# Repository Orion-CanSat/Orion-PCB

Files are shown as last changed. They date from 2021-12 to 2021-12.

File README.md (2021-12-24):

# Orion II PCB

&nbsp;
## Who are we?
We are a team composed of 12 students of the [Model High School “Evangeliki Scholi Smyrna”](http://lyk-evsch-n-smyrn.att.sch.gr/wordpress/?p=1322). For the fourth consecutive time we are participating in the Panhellenic competition "[CanSat in Greece](https://cansat.gr/)", a qualifier of the Pan-European competition "[CanSats in Europe](http://www.esa.int/SPECIALS/CanSat/SEMXTDCKP6G_0.html)", organized by ESA (European Space Agency) for the last 8 years. Our team is called Orion II and our supervisor is Dr. Christos Fanidis.

&nbsp;
## Our Inspiration

&nbsp;
## Do you want to contibute?
Unfortuannately this repository does not accept any new commits, or merge requests. You are free to fork it and work on your own.

&nbsp;
## PCB Desgin
These PCBs where designed by Danae Veli.

&nbsp;
## Meet our Team (In alphabetical order)
| Name | Role | Introduction |
| --- | --- | --- |
| __Danae Veli__ | Head of Electrical Engineering | My name is Danae Veli and I am a student at Model High School "Evangeliki Scholi Smyrna". I am a part of team Orion II and I am in charge of the electrical design. My main duty is to design the PCBs for the project. |
| [__Dionysios Angelopoulos__](https://github.com/DennisAngelo) | Head of Mechanical Engineering and Control Systems Development | My name is Dionysios Angelopoulos. I am a greek High School student attending Model High School “Evangeliki Scholi Smyrna”. I am the head of Mechanical Engineering in Orion II. My main duty was to 3D model the cansat and to design and tune the control system for the cansat.  |
| [__Jim Balatos__](https://github.com/jbalatos) | Head of Software Engineering | My name is Jim Balatos. I am a greek High School student attending Model High School “Evangeliki Scholi Smyrna”. I am the head of Software Engineering in Orion II. My main duty was to write the Live Server of our mission. |
| __Giorgos Kaltsis__ | Senior Data Analyst | |
| [__Konstantinos Kritharidis__](https://github.com/konstantinosk31) | Head of Retrieval System | My name is Konstantinos Kritharidis. I am a greek High School student attending The American College of Greece - Pierce. I am the head of the Retrieval System in Orion II. My main duty was to design and create the ram-air parachute for the CanSat. |
| [__Rikarnto Bariampa__](https://github.com/richardbar) | Head of Telemetry and Senior Software Engineer | My name is Rikarnto Bariampa. I am a greek High School student attending Model High School “Evangeliki Scholi Smyrna”. I am the head of Telemetry and a Senior Software Engineer in Orion II. My main duty was to write the onboard code for the CanSat. |

&nbsp;
## Want to reach us?
If you have any question, please feel free to reach us in one of the following ways:
* [__Email__](mailto:orioncantgr@gmail.com)
* [__Facebook__](https://www.facebook.com/orioncansatteam)
* [__Twitter__](https://twitter.com/OrionCanSat2020)

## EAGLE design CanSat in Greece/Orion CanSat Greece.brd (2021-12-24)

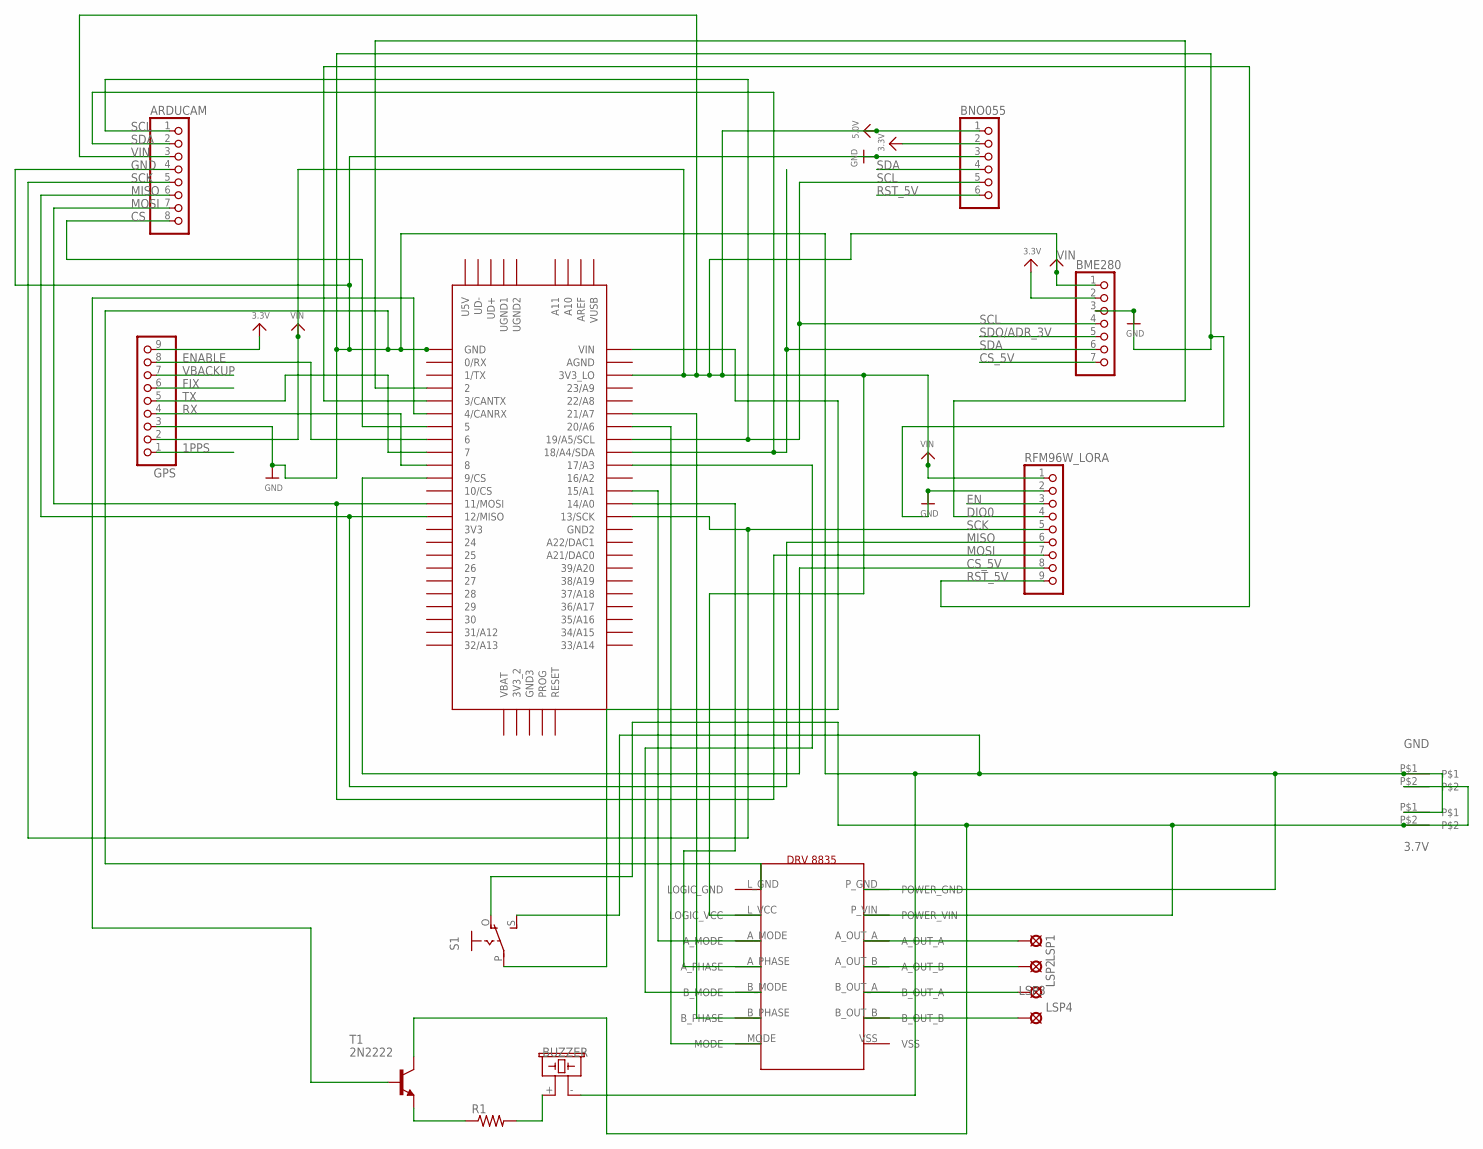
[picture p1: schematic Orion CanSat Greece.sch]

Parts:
ARDUCAM: PINHD-1X8BIG; 1X08-BIG
BME280: HEADER-1X770MIL; 1X07_ROUND_70
BNO055: HEADER-1X676MIL; 1X06_ROUND_76
GPS: HEADER-1X970MIL; 1X09_ROUND_70
LSP1, LSP2, LSP3, LSP4: LSP13
R1: FLIPFLOP-RES; 0805-THM
RFM96W_LORA: HEADER-1X970MIL; 1X09_ROUND_70
S1: EG1218S; EG1218
SG2: F/CM12P
T1: 2N2222; TO92-EBC-OVAL
U$1: TEENSY_3.5/3.6
U$7, U$8: 2PINS
U$15: DRV8835

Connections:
1PPS: GPS.1
3.3V: BME280.2, BNO055.2, GPS.9
3V7: S1.P, U$1.VIN
BZPWR: R1.2, SG2.+ (1)
CS: ARDUCAM.8, U$1.5
CS_5V: BME280.7, RFM96W_LORA.8, U$1.9/CS
DIO0: RFM96W_LORA.4, U$1.2
EN: RFM96W_LORA.3
ENABLE: GPS.8, U$1.6
FIX: GPS.6
GND: ARDUCAM.4, BME280.3, BNO055.3, GPS.3, RFM96W_LORA.2, S1.S, SG2.- (2), U$1.GND, U$7.P$1, U$8.P$1, U$15.L_GND (LOGIC_GND), U$15.P_GND (POWER_GND)
MISO: ARDUCAM.6, RFM96W_LORA.6, U$1.12/MISO
MOSI: ARDUCAM.7, RFM96W_LORA.7, U$1.11/MOSI
unnamed: R1.1, T1.E
unnamed: U$1.20/A6, U$15.MODE
unnamed: T1.B, U$1.4/CANRX
unnamed: U$1.21/A7, U$15.B_PHASE
unnamed: U$1.14/A0, U$15.A_PHASE
unnamed: U$1.15/A1, U$15.A_MODE
unnamed: U$1.17/A3, U$15.B_MODE
unnamed: LSP1.MP, U$15.A_OUT_A
unnamed: LSP2.MP, U$15.A_OUT_B
unnamed: LSP3.MP, U$15.B_OUT_A
unnamed: LSP4.MP, U$15.B_OUT_B
RST_5V: BNO055.6, RFM96W_LORA.9, U$1.3/CANTX
RX: GPS.4, U$1.8
SCK: ARDUCAM.5, RFM96W_LORA.5, U$1.13/SCK
SCL: ARDUCAM.1, BME280.4, BNO055.5, U$1.19/A5/SCL
SDA: ARDUCAM.2, BME280.6, BNO055.4, U$1.18/A4/SDA
SDO/ADR_3V: BME280.5
TX: GPS.5, U$1.7
VBACKUP: GPS.7
VBAT: S1.O, T1.C, U$7.P$2, U$8.P$2, U$15.P_VIN (POWER_VIN)
VIN: ARDUCAM.3, BME280.1, BNO055.1, GPS.2, RFM96W_LORA.1, U$1.3V3_LO, U$15.L_VCC (LOGIC_VCC)

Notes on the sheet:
3.7V
GND
BUZZER
VIN

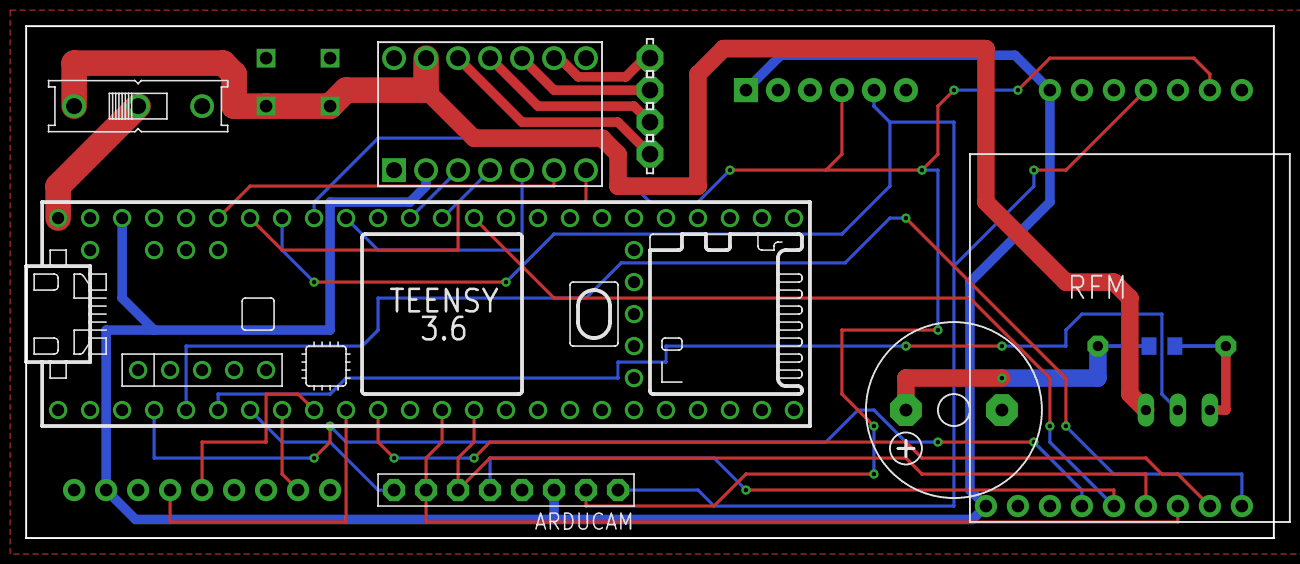
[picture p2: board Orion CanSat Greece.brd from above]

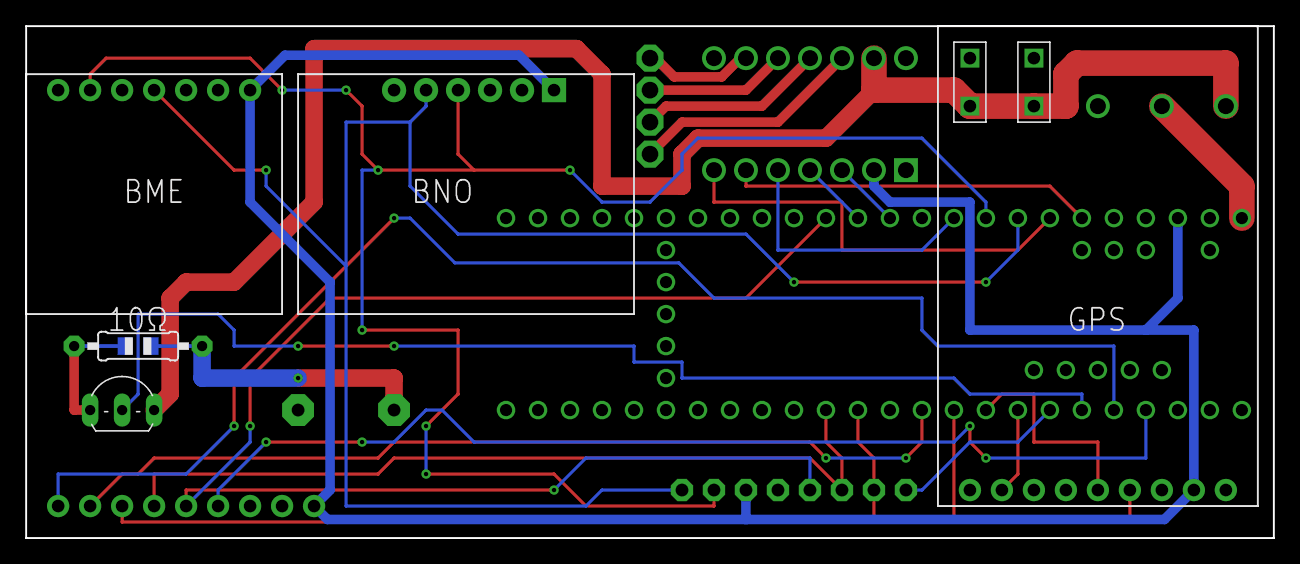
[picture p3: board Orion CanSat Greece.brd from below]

Board: 2 copper layers, 99.1 x 40.6 mm, 17 parts (4 on the bottom side), 29 nets.

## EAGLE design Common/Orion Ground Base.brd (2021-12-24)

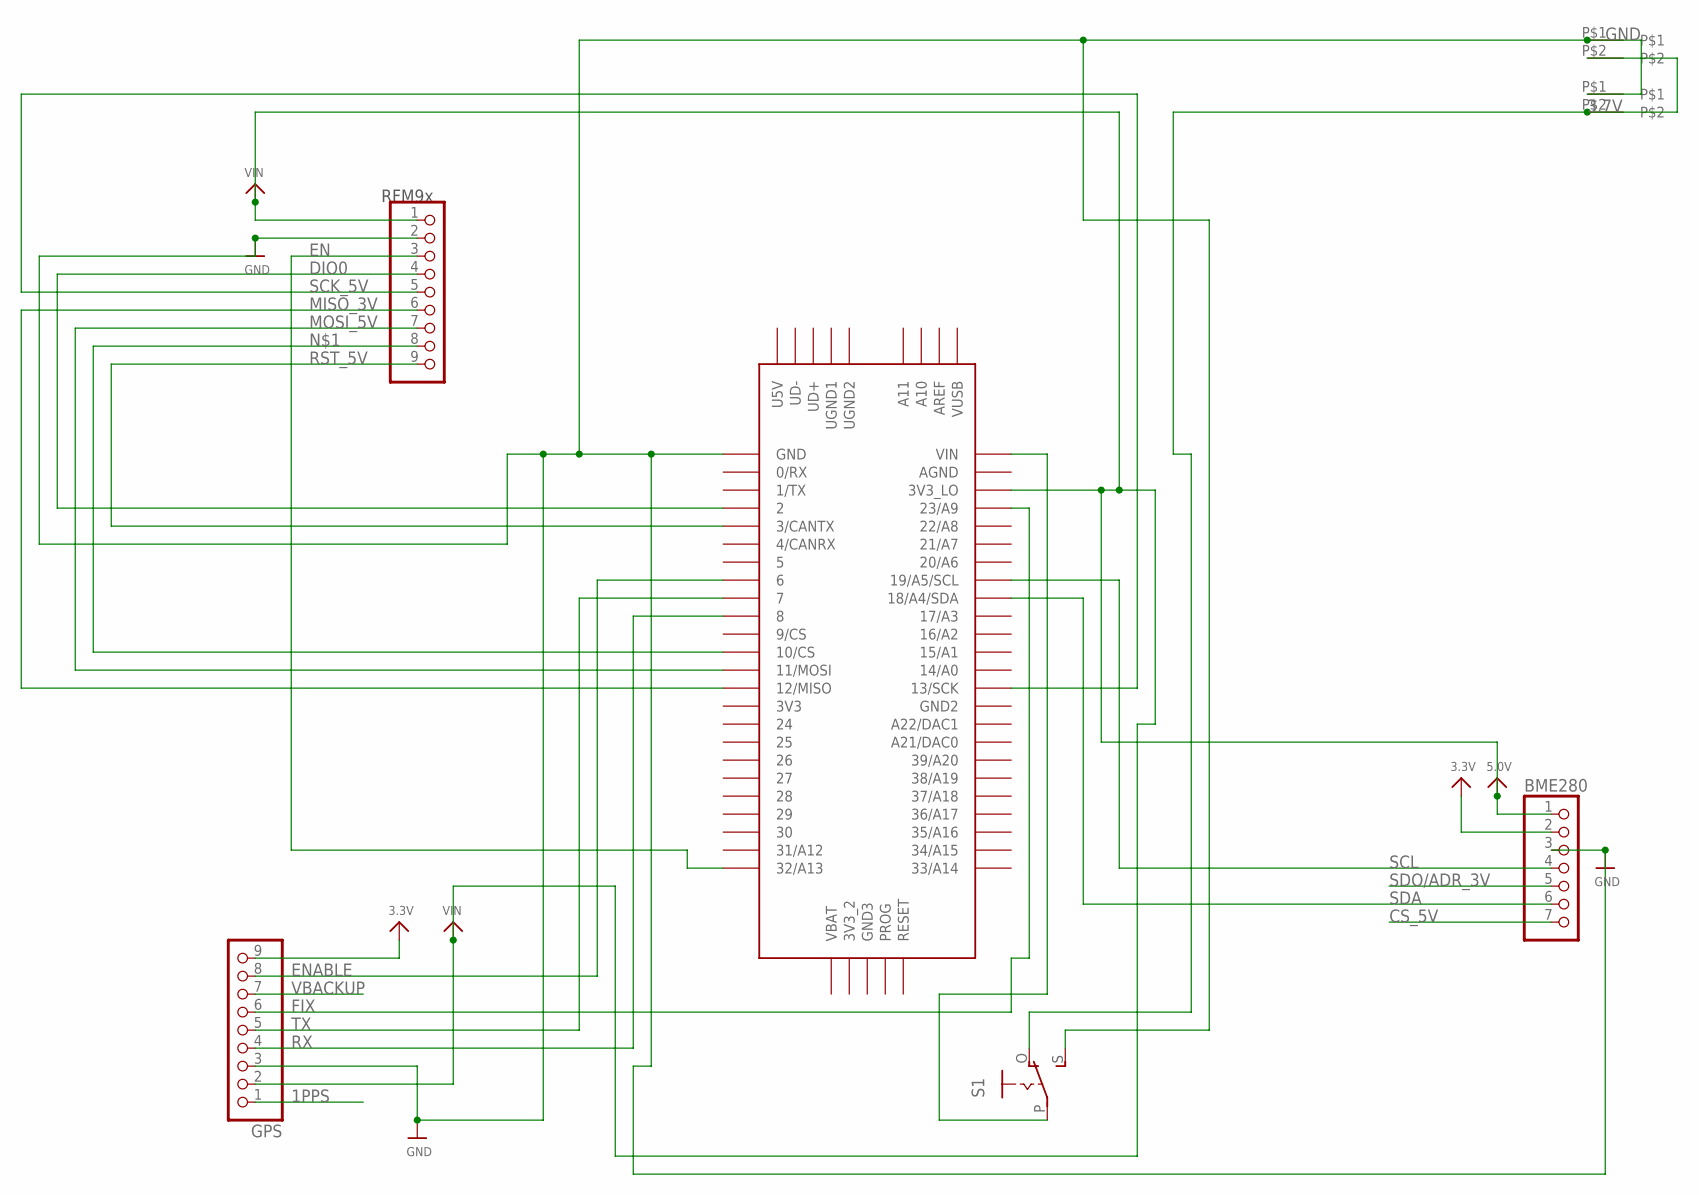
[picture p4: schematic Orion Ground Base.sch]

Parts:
BME280: HEADER-1X770MIL; 1X07_ROUND_70
GPS: HEADER-1X970MIL; 1X09_ROUND_70
JP3: HEADER-1X970MIL; 1X09_ROUND_70
S1: EG1218S; EG1218
U$1: TEENSY_3.5/3.6
U$7, U$8: 2PINS

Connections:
1PPS: GPS.1
3.3V: BME280.2, GPS.9
CS_5V: BME280.7
DIO0: JP3.4, U$1.2
EN: JP3.3, U$1.32/A13
ENABLE: GPS.8, U$1.6
FIX: GPS.6, U$1.23/A9
GND: BME280.3, GPS.3, JP3.2, S1.S, U$1.GND, U$7.P$1, U$8.P$1
MISO_3V: JP3.6, U$1.12/MISO
MOSI_5V: JP3.7, U$1.11/MOSI
unnamed: JP3.8, U$1.9/CS, U$1.10/CS
unnamed: S1.P, U$1.VIN
unnamed: S1.O, U$7.P$2, U$8.P$2
RST_5V: JP3.9, U$1.3/CANTX
RX: GPS.4, U$1.8
SCK_5V: JP3.5, U$1.13/SCK
SCL: BME280.4, U$1.19/A5/SCL
SDA: BME280.6, U$1.18/A4/SDA
SDO/ADR_3V: BME280.5
TX: GPS.5, U$1.7
VBACKUP: GPS.7
VIN: BME280.1, GPS.2, JP3.1, U$1.3V3_LO

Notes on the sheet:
RFM9x
3.7V
GND

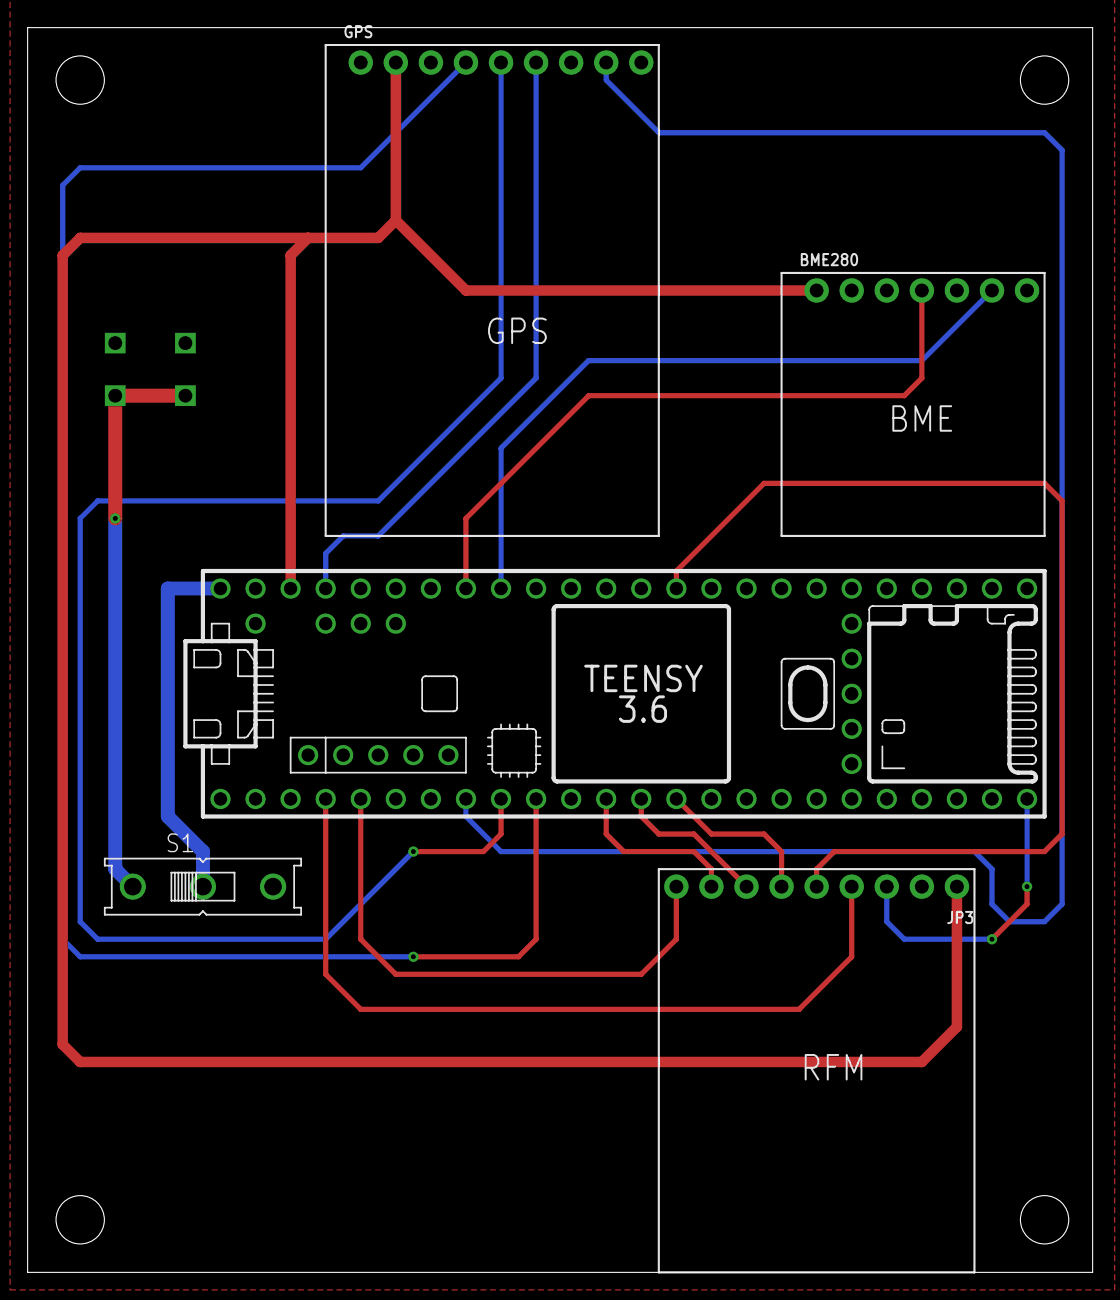
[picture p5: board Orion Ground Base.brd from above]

Board: 2 copper layers, 77.1 x 90.2 mm, 7 parts (0 on the bottom side), 18 nets.

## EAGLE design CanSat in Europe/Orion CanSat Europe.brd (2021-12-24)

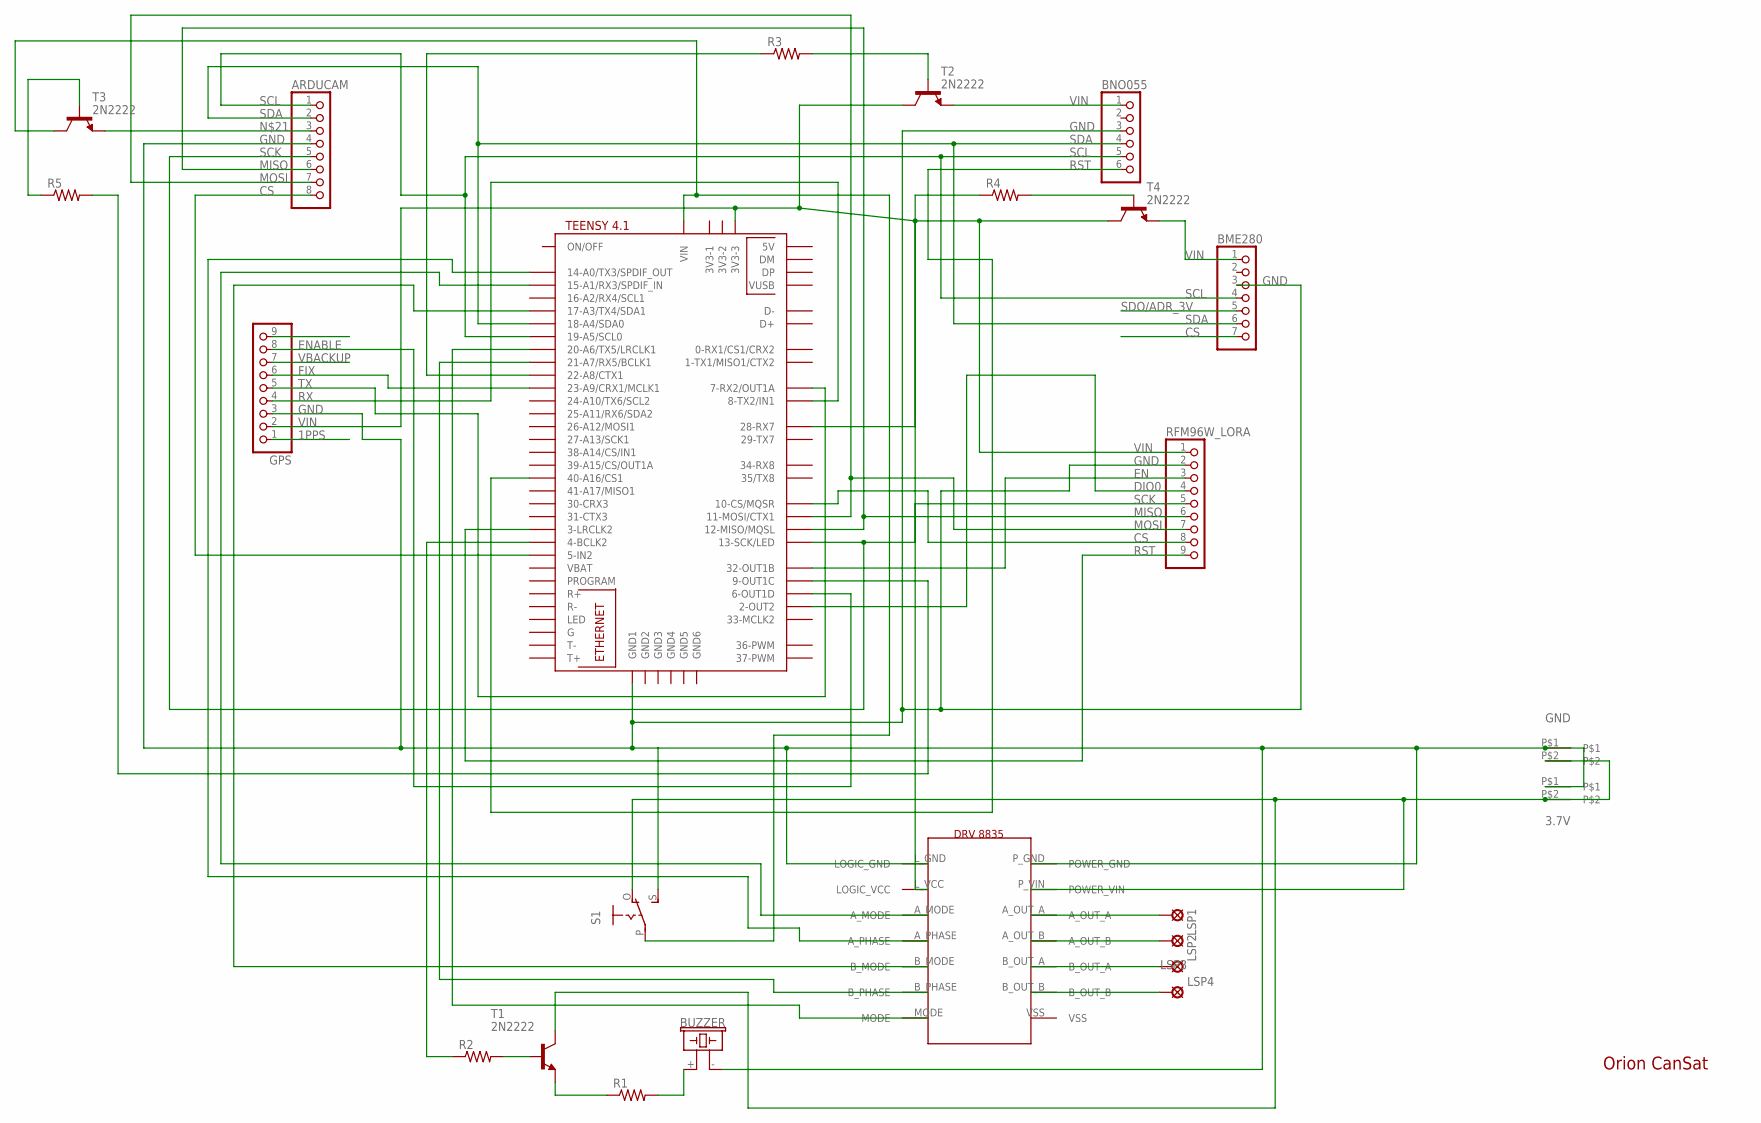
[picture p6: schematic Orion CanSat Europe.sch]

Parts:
ARDUCAM: PINHD-1X8BIG; 1X08-BIG
BME280: HEADER-1X770MIL; 1X07_ROUND_70
BNO055: HEADER-1X676MIL; 1X06_ROUND_76
GPS: HEADER-1X970MIL; 1X09_ROUND_70
LSP1, LSP2, LSP3, LSP4: LSP13
R1, R2, R3, R4, R5: FLIPFLOP-RES; 0805-THM
RFM96W_LORA: HEADER-1X970MIL; 1X09_ROUND_70
S1: EG1218S; EG1218
SG2: F/CM12P
T1, T2, T3, T4: 2N2222; TO92-EBC-OVAL
U$1: DRV8835
U$5: TEENSY41
U$7, U$8: 2PINS

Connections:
1PPS: GPS.1
BZPWR: R1.2, SG2.+ (1)
CS: ARDUCAM.8, U$5.5-IN2
CS_5V: BME280.7, RFM96W_LORA.8, U$5.10-CS\MQSR (10-CS/MQSR)
DIO0: RFM96W_LORA.4, U$5.2-OUT2
EN: RFM96W_LORA.3, U$5.32-OUT1B
ENABLE: GPS.8, U$5.6-OUT1D
FIX: GPS.6, U$5.23-A9/CRX1/MCLK1
GND: ARDUCAM.4, BME280.3, BNO055.3, GPS.3, RFM96W_LORA.2, S1.S, SG2.- (2), U$1.L_GND (LOGIC_GND), U$1.P_GND (POWER_GND), U$5.GND1, U$7.P$1, U$8.P$1
MISO: ARDUCAM.6, RFM96W_LORA.6, U$5.12-MISO/MQSL
MOSI: ARDUCAM.7, RFM96W_LORA.7, U$5.11-MOSI/CTX1
unnamed: R1.1, T1.E
unnamed: U$1.MODE, U$5.20-A6/TX5/LRCLK1
unnamed: U$1.A_PHASE, U$5.14-A0/TX3/SPDIF_OUT
unnamed: R3.1, U$5.22-A8/CTX1
unnamed: U$1.B_PHASE, U$5.21-A7/RX5/BCLK1
unnamed: R5.2, U$5.9-OUT1C
unnamed: U$1.A_MODE, U$5.15-A1/RX3/SPDIF_IN
unnamed: R4.1, U$5.28-RX7
unnamed: LSP1.MP, U$1.A_OUT_A
unnamed: R2.2, T1.B
unnamed: LSP2.MP, U$1.A_OUT_B
unnamed: LSP3.MP, U$1.B_OUT_A
unnamed: LSP4.MP, U$1.B_OUT_B
unnamed: R4.2, T4.B
unnamed: R3.2, T2.B
unnamed: GPS.2, RFM96W_LORA.1, T2.C, T4.C, U$1.L_VCC (LOGIC_VCC), U$5.3V3-3
unnamed: U$1.B_MODE, U$5.17-A3/TX4/SDA1
unnamed: BNO055.1, T2.E
unnamed: BME280.1, T4.E
unnamed: ARDUCAM.3, T3.E
unnamed: S1.P, T3.C, U$5.VIN
unnamed: R5.1, T3.B
unnamed: S1.O, T1.C, U$1.P_VIN (POWER_VIN), U$7.P$2, U$8.P$2
unnamed: R2.1, U$5.4-BCLK2
RST: BNO055.6, RFM96W_LORA.9, U$5.3-LRCLK2, U$5.40-A16/CS1
RX: GPS.4, U$5.8-TX2/IN1
SCK: ARDUCAM.5, RFM96W_LORA.5, U$5.13-SCK/LED
SCL: ARDUCAM.1, BME280.4, BNO055.5, U$5.19-A5/SCL0
SDA: ARDUCAM.2, BME280.6, BNO055.4, U$5.18-A4/SDA0
SDO/ADR_3V: BME280.5
TX: GPS.5, U$5.7-RX2/OUT1A
VBACKUP: GPS.7

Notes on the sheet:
3.7V
GND
BUZZER
VIN
Orion CanSat

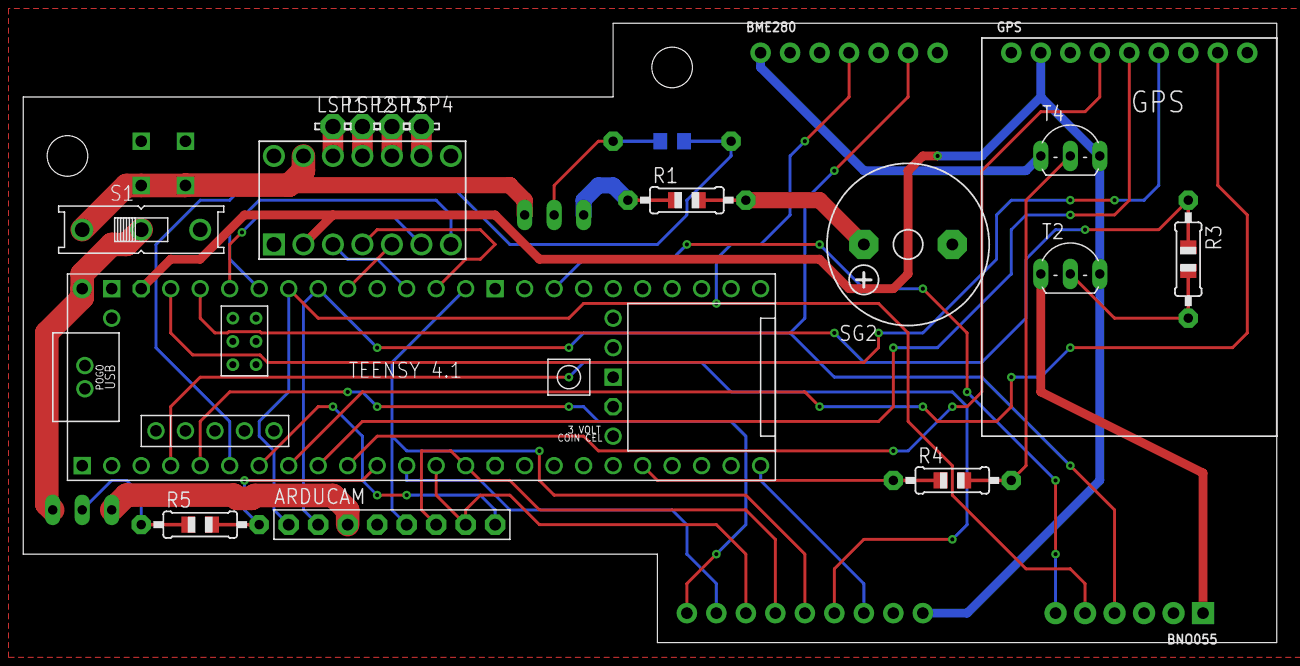
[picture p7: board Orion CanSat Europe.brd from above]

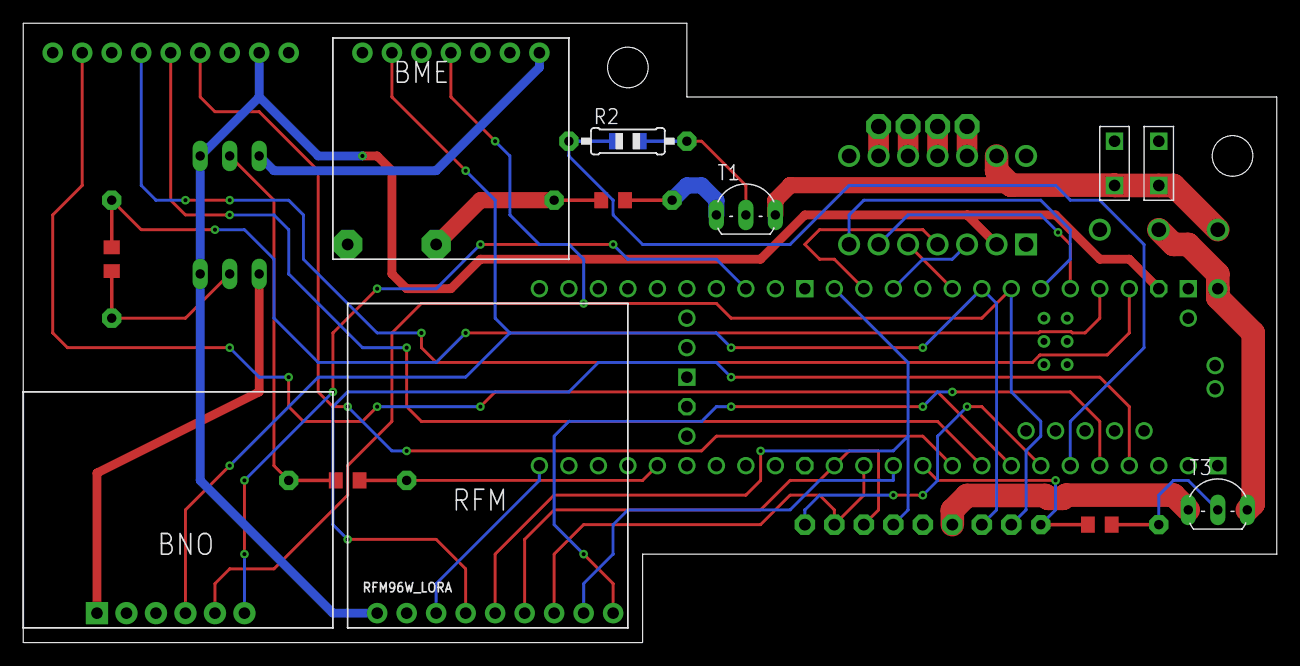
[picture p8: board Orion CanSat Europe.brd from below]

Board: 2 copper layers, 108.0 x 53.3 mm, 24 parts (4 on the bottom side), 40 nets.

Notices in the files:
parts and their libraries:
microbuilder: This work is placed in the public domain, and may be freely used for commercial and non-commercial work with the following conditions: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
